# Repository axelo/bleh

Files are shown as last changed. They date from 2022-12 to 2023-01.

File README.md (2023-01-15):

# BLEH-1

Simple 8-bit processor with an 8-bit data bas, a 16-bit address bus and 8 in/out ports. Code and data is shared (Von Neumann architecture).

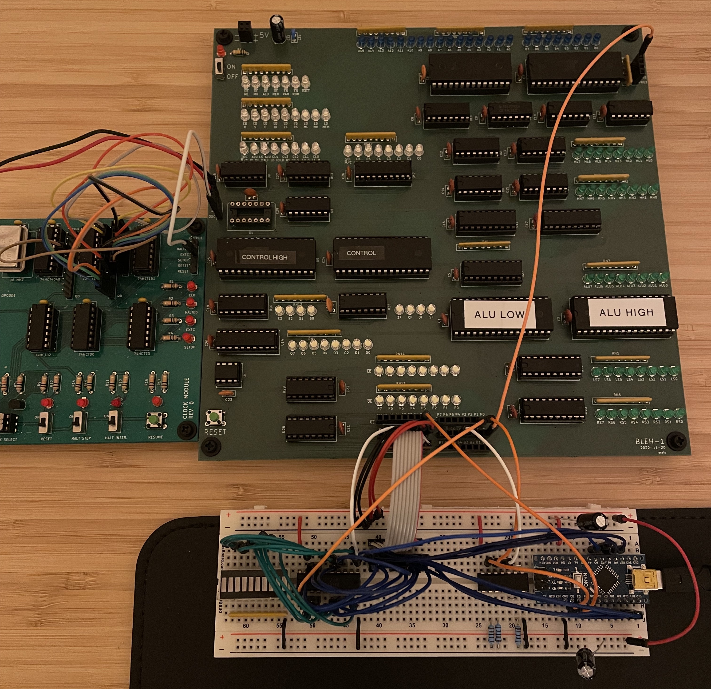
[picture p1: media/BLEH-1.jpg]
BLEH-1


## Videos

https://user-images.githubusercontent.com/40123/208307373-e6665b57-9ac1-4e1d-83b8-c3a5a47eff5f.mp4

https://user-images.githubusercontent.com/40123/209331055-dc162672-afca-4b18-9f8f-d3effcc05d64.mp4

## Logic blocks

### Memory backed registers

The last 16 bytes of memory are used for storing data and address registers (instruction registers) in addition to temporary storage during microcode steps.

8-bit data registers: `a`, `b`, `c` and `d`

16-bit address registers: `i` and `j`

8-bit special registers: `sp`

### ALU

Two 8-bit registers `LS` and `RS` makes up the operands to the ALU. Neither are accessible from software. Two ROMs makes up a lookup table for different ALU operation. A 4-bit flag register is available for storing `zf`, `cf`, `of` and `sf`.

### Control

Two ROMs together with a 4-bit step counter, an 8-bit opcode register and the flags register makes up a lookup table for different microcode steps for different instructions. The step counter is cleared on reset.

### Memory

Two 8-bit register `ML` and `MH` makes up the 16-bit address bus. Neither are accessible from software. The registers are cleared on reset making program execution start at `0x0000`.

#### Stack

The high part of the stack is locked at `0xff`. The low part is loaded by setting the `sp` instruction register. The stack grows upwards towards `0xffff`. Usually the `sp` is loaded with `0xff` making the first `push` at `0xff00`.

#### Constant and ML/MH toggle

One control signal toggles if the address bus is based on `ML`/`MH` or the low 4-bits of the constant register `or`:ed by `0xfff0`. This is used to address the instruction registers during microcode steps.

#### Memory map

    0x0000 - 0x7fff: ROM
    0x8000 - 0xfff0: RAM
    0xfff0 - 0xffff: RAM containing instruction registers

### Clock

The input clock source is divided into two equally long phases named setup and execute. The setup phase settles the control signals and the execute phase latches the input source (the data bus for example).

### Data bus

The data bus is pulled high so if nothing is asserted then `0xff` will be read.

## Software

### Compile

Requires that the `bleh_instructions.asm` [customasm](https://github.com/hlorenzi/customasm) ruledef file exists:

    ./compile_and_run.zsh customasm.c

Then compile your program using `customasm`, for example:

    customasm -q ./software/test_lcd.asm --print --format intelhex

### Loading software

Using the [arduino boot device](./arduino/BootDeviceSketch/BootDeviceSketch.ino), connect a serial monitor and paste Intel Hex format of the program.

## Emulator

### Compile

    ./compile.zsh emulator.c

### Run

Requires that the control and ALU ROM binaries are built:

    ./compile_and_run.zsh control.c && ./compile_and_run.zsh alu.c

Then compile your program using `customasm`:

    customasm <PROGRAM TO RUN>.asm --format binary --output <PROGRAM TO RUN>.bin

Then finally run the program using the emulator:

    ./bin/emulator <PROGRAM TO RUN>.bin [CLOCK FREQUENCY IN HZ]

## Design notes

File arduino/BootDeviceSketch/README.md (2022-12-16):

arduino-cli compile --fqbn arduino:avr:nano BootDeviceSketch/BootDeviceSketch.ino

arduino-cli upload -p /dev/cu.usbserial-10 --fqbn arduino:avr:nano:cpu=atmega328old BootDeviceSketch/BootDeviceSketch.ino

arduino-cli monitor -p /dev/cu.usbserial-10 -c baudrate=115200

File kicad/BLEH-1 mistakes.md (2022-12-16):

## Mistakes

### 1

D7 Led pin 2 is connected to BUS2, should be BUS1
D8 Led pin 2 is connected to BUS1, should be BUS2

### 2

U28 pin 9 connected to ~{LD} S, should be ~{LD} LS

### 3

All bypass capacitor footprints should be 5mm instead of 2.5mm.

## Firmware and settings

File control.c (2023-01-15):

#include <assert.h> // assert
#include <stdbool.h> // bool
#include <stdint.h> // uint*_t
#include <stdio.h> // FILE, f* functions

#include "alu_op.h"
#include "opcode.h"

#define CONTROL_ROM_SIZE (1 << 17)

#define PIN_OPCODE_0 0
#define PIN_OPCODE_1 1
#define PIN_OPCODE_2 2
#define PIN_OPCODE_3 3
#define PIN_OPCODE_4 4
#define PIN_OPCODE_5 5
#define PIN_OPCODE_6 6
#define PIN_OPCODE_7 7

#define PIN_HIGH_SLICE 10

#define PIN_FLAG_0_ZERO 11
#define PIN_FLAG_1_CARRY 9
#define PIN_FLAG_2_OVERFLOW 8
#define PIN_FLAG_3_SIGN 13

#define PIN_STEP_0 12
#define PIN_STEP_1 15
#define PIN_STEP_2 16
#define PIN_STEP_3 14

#define CE_M_NOT_LD_C (1 << 0)
#define LD_O_NOT_LD_C (1 << 1)
#define LD_S_NOT_LD_C (1 << 2)
#define LD_RS_NOT_LD_C (1 << 3)
#define LD_IO_NOT_LD_C (1 << 4)
#define C_LS_ALU_Q (1 << 5)
#define HALT_NOT_LD_C (1 << 5)
#define LD_C (1 << 6)
#define TG_M_C (1 << 7)
#define LD_MEM (1 << 8)
#define LD_LS (1 << 9)
#define LD_ML (1 << 10)
#define LD_MH (1 << 11)
#define OE_ML (1 << 12)
#define OE_MH (1 << 13)
#define OE_ALU (1 << 14)
#define OE_MEM (1 << 15)

#define ACTIVE_LOW_MASK (LD_C | LD_LS | LD_ML | LD_MH | OE_ML | OE_MH | OE_ALU | OE_MEM)

#define FETCH_OPCODE (OE_MEM | LD_O_NOT_LD_C | CE_M_NOT_LD_C)

#define C_A (0x0)
#define C_B (0x1)
#define C_C (0x2)
#define C_D (0x3)
#define C_SPL (0x4)
#define C_IL (0x5)
#define C_IH (0x6)
#define C_JL (0x7)
#define C_JH (0x8)
// #define C_ (0x9)
// #define C_ (0xa)
#define C_TL (0xb)
#define C_TH (0xc)
#define C_UL (0xd)
// #define C_ (0xe)
// #define C_ (0xf)

_Static_assert(ALU_OP_DEC_LS == C_SPL, "C_SPL must be identical to ALU_OP_DEC_LS");

static uint16_t opcode_nop(uint8_t step) {
    switch (step) {
    case 0: return FETCH_OPCODE;
    case 1: return 0;
    case 2: return 0;
    case 3: return 0;
    case 4: return 0;
    case 5: return 0;
    case 6: return 0;
    case 7: return LD_S_NOT_LD_C;
    default: return HALT_NOT_LD_C;
    }
}

static uint16_t opcode_halt(uint8_t step) {
    switch (step) {
    case 0: return FETCH_OPCODE;
    case 1: return HALT_NOT_LD_C;
    case 2: return LD_S_NOT_LD_C;
    default: return HALT_NOT_LD_C;
    }
}

static uint16_t opcode_ld_reg_imm8(uint8_t dest_const_reg, uint8_t step) {
    switch (step) {
    case 0: return FETCH_OPCODE;
    case 1: return OE_MEM | LD_LS | C_LS_ALU_Q | dest_const_reg | LD_C | TG_M_C;
    case 2: return OE_ALU | LD_MEM | TG_M_C | CE_M_NOT_LD_C | LD_S_NOT_LD_C;
    default: return HALT_NOT_LD_C;
    }
}

static uint16_t opcode_ld_index_imm16(uint8_t dest_const_index_l, uint8_t step) {
    switch (step) {
    case 0: return FETCH_OPCODE;
    case 1: return OE_MEM | LD_LS | C_LS_ALU_Q | dest_const_index_l | LD_C | TG_M_C;
    case 2: return OE_ALU | LD_MEM | TG_M_C | CE_M_NOT_LD_C;
    case 3: return OE_MEM | LD_LS | C_LS_ALU_Q | (dest_const_index_l + 1) | LD_C | TG_M_C;
    case 4: return OE_ALU | LD_MEM | TG_M_C | CE_M_NOT_LD_C | LD_S_NOT_LD_C;
    default: return HALT_NOT_LD_C;
    }
}

static uint16_t opcode_ld_reg_index_ptr(uint8_t dest_const_reg, uint8_t const_index_l, uint8_t step) {
    switch (step) {
    case 0: return FETCH_OPCODE;
    case 1: return C_TL | LD_C | TG_M_C;
    case 2: return OE_ML | LD_MEM | C_TH | LD_C;
    case 3: return OE_MH | LD_MEM | const_index_l | LD_C;
    case 4: return OE_MEM | LD_ML | (const_index_l + 1) | LD_C;
    case 5: return OE_MEM | LD_MH | TG_M_C;
    case 6: return OE_MEM | LD_LS | C_LS_ALU_Q | dest_const_reg | LD_C | TG_M_C;
    case 7: return OE_ALU | LD_MEM | C_TL | LD_C;
    case 8: return OE_MEM | LD_ML | C_TH | LD_C;
    case 9: return OE_MEM | LD_MH | TG_M_C | LD_S_NOT_LD_C;
    default: return HALT_NOT_LD_C;
    }
}

static uint16_t opcode_ld_reg_index_ptr_inc1(uint8_t dest_const_reg, uint8_t const_index_l, uint8_t step) {
    switch (step) {
    case 0: return FETCH_OPCODE;
    case 1: return C_TL | LD_C | TG_M_C;
    case 2: return OE_ML | LD_MEM | C_TH | LD_C;
    case 3: return OE_MH | LD_MEM | const_index_l | LD_C;
    case 4: return OE_MEM | LD_ML | (const_index_l + 1) | LD_C;
    case 5: return OE_MEM | LD_MH | TG_M_C;
    case 6: return OE_MEM | LD_LS | CE_M_NOT_LD_C | TG_M_C;
    case 7: return OE_MH | LD_MEM | const_index_l | LD_C;
    case 8: return OE_ML | LD_MEM | C_LS_ALU_Q | dest_const_reg | LD_C;
    case 9: return OE_ALU | LD_MEM | C_TL | LD_C;
    case 10: return OE_MEM | LD_ML | C_TH | LD_C;
    case 11: return OE_MEM | LD_MH | TG_M_C | LD_S_NOT_LD_C;
    default: return HALT_NOT_LD_C;
    }
}

static uint16_t opcode_ld_index_ptr_reg(uint8_t const_index_l, uint8_t dest_const_reg, uint8_t step) {
    switch (step) {
    case 0: return FETCH_OPCODE;
    case 1: return C_TL | LD_C | TG_M_C;
    case 2: return OE_ML | LD_MEM | C_TH | LD_C;
    case 3: return OE_MH | LD_MEM | const_index_l | LD_C;
    case 4: return OE_MEM | LD_ML | (const_index_l + 1) | LD_C;
    case 5: return OE_MEM | LD_MH | C_LS_ALU_Q | dest_const_reg | LD_C;
    case 6: return OE_MEM | LD_LS | TG_M_C;
    case 7: return OE_ALU | LD_MEM | C_TL | LD_C | TG_M_C;
    case 8: return OE_MEM | LD_ML | C_TH | LD_C;
    case 9: return OE_MEM | LD_MH | TG_M_C | LD_S_NOT_LD_C;
    default: return HALT_NOT_LD_C;
    }
}

static uint16_t opcode_ld_index_ptr_inc1_reg(uint8_t const_index_l, uint8_t dest_const_reg, uint8_t step) {
    switch (step) {
    case 0: return FETCH_OPCODE;
    case 1: return dest_const_reg | LD_C | TG_M_C;
    case 2: return OE_MEM | LD_LS | C_TL | LD_C;
    case 3: return OE_ML | LD_MEM | C_TH | LD_C;
    case 4: return OE_MH | LD_MEM | const_index_l | LD_C;
    case 5: return OE_MEM | LD_ML | C_LS_ALU_Q | (const_index_l + 1) | LD_C;
    case 6: return OE_MEM | LD_MH | TG_M_C;
    case 7: return OE_ALU | LD_MEM | CE_M_NOT_LD_C | TG_M_C;
    case 8: return OE_MH | LD_MEM | const_index_l | LD_C;
    case 9: return OE_ML | LD_MEM | C_TL | LD_C;
    case 10: return OE_MEM | LD_ML | C_TH | LD_C;
    case 11: return OE_MEM | LD_MH | TG_M_C | LD_S_NOT_LD_C;
    default: return HALT_NOT_LD_C;
    }
}

static uint16_t opcode_ld_index_ptr_reg_reg(uint8_t const_index_l, uint8_t src_const_reg_h, uint8_t src_const_reg_l, uint8_t step) {
    switch (step) {
    case 0: return FETCH_OPCODE;
    case 1: return C_TL | LD_C | TG_M_C;
    case 2: return OE_ML | LD_MEM | C_TH | LD_C;
    case 3: return OE_MH | LD_MEM | const_index_l | LD_C;
    case 4: return OE_MEM | LD_ML | (const_index_l + 1) | LD_C;
    case 5: return OE_MEM | LD_MH | C_LS_ALU_Q | src_const_reg_l | LD_C;
    case 6: return OE_MEM | LD_LS | TG_M_C;
    case 7: return OE_ALU | LD_MEM | C_LS_ALU_Q | src_const_reg_h | LD_C | TG_M_C;
    case 8: return OE_MEM | LD_LS | CE_M_NOT_LD_C | TG_M_C;
    case 9: return OE_ALU | LD_MEM | C_TL | LD_C | TG_M_C;
    case 10: return OE_MEM | LD_ML | C_TH | LD_C;
    case 11: return OE_MEM | LD_MH | TG_M_C | LD_S_NOT_LD_C;
    default: return HALT_NOT_LD_C;
    }
}

static uint16_t opcode_ld_reg_reg_index_ptr(uint8_t dest_const_reg_h, uint8_t dest_const_reg_l, uint8_t const_index_l, uint8_t step) {
    switch (step) {
    case 0: return FETCH_OPCODE;
    case 1: return C_TL | LD_C | TG_M_C;
    case 2: return OE_ML | LD_MEM | C_TH | LD_C;
    case 3: return OE_MH | LD_MEM | const_index_l | LD_C;
    case 4: return OE_MEM | LD_ML | (const_index_l + 1) | LD_C;
    case 5: return OE_MEM | LD_MH | C_LS_ALU_Q | dest_const_reg_l | LD_C | TG_M_C;
    case 6: return OE_MEM | LD_LS | CE_M_NOT_LD_C | TG_M_C;
    case 7: return OE_ALU | LD_MEM | C_LS_ALU_Q | dest_const_reg_h | LD_C | TG_M_C;
    case 8: return OE_MEM | LD_LS | TG_M_C;
    case 9: return OE_ALU | LD_MEM | C_TL | LD_C;
    case 10: return OE_MEM | LD_ML | C_TH | LD_C;
    case 11: return OE_MEM | LD_MH | TG_M_C | LD_S_NOT_LD_C;
    default: return HALT_NOT_LD_C;
    }
}

static u_int16_t opcode_ld_reg_reg(uint8_t dest_const_reg, uint8_t src_const_reg, uint8_t step) {
    switch (step) {
    case 0: return FETCH_OPCODE;
    case 1: return src_const_reg | LD_C | TG_M_C;
    case 2: return OE_MEM | LD_LS | C_LS_ALU_Q | dest_const_reg | LD_C;
    case 3: return OE_ALU | LD_MEM | TG_M_C | LD_S_NOT_LD_C;
    default: return HALT_NOT_LD_C;
    }
}

static uint16_t opcode_alu_op_reg(ALU_OP alu_op, uint8_t dest_and_src_const_reg, uint8_t step) {
    switch (step) {
    case 0: return FETCH_OPCODE;
    case 1: return dest_and_src_const_reg | LD_C | TG_M_C;
    case 2: return OE_MEM | LD_LS | (uint8_t)alu_op | LD_C;
    case 3: return OE_ALU | LD_LS | C_LS_ALU_Q | dest_and_src_const_reg | LD_C;
    case 4: return OE_ALU | LD_MEM | TG_M_C | LD_S_NOT_LD_C;
    default: return HALT_NOT_LD_C;
    }
}

static uint16_t opcode_alu_op_reg_reg(ALU_OP alu_op, uint8_t dest_const_reg, uint8_t src_const_reg, uint8_t step) {
    switch (step) {
    case 0: return FETCH_OPCODE;
    case 1: return dest_const_reg | LD_C | TG_M_C;
    case 2: return OE_MEM | LD_LS | src_const_reg | LD_C;
    case 3: return OE_MEM | LD_RS_NOT_LD_C;
    case 4: return (uint8_t)alu_op | LD_C;
    case 5: return OE_ALU | LD_LS | C_LS_ALU_Q | dest_const_reg | LD_C;
    case 6: return OE_ALU | LD_MEM | TG_M_C | LD_S_NOT_LD_C;
    default: return HALT_NOT_LD_C;
    }
}

static uint16_t opcode_alu_op_reg_imm8(ALU_OP alu_op, uint8_t dest_const_reg, uint8_t step) {
    switch (step) {
    case 0: return FETCH_OPCODE;
    case 1: return OE_MEM | LD_RS_NOT_LD_C | CE_M_NOT_LD_C;
    case 2: return dest_const_reg | LD_C | TG_M_C;
    case 3: return OE_MEM | LD_LS | (uint8_t)alu_op | LD_C;
    case 4: return OE_ALU | LD_LS | C_LS_ALU_Q | dest_const_reg | LD_C;
    case 5: return OE_ALU | LD_MEM | TG_M_C | LD_S_NOT_LD_C;
    default: return HALT_NOT_LD_C;
    }
}

static uint16_t opcode_alu_cmp_reg_imm8(uint8_t const_reg, uint8_t step) {
    switch (step) {
    case 0: return FETCH_OPCODE;
    case 1: return OE_MEM | LD_RS_NOT_LD_C | CE_M_NOT_LD_C;
    case 2: return const_reg | LD_C | TG_M_C;
    case 3: return OE_MEM | LD_LS | ALU_OP_LS_SUB_RS | LD_C;
    case 4: return OE_ALU | LD_LS | TG_M_C | LD_S_NOT_LD_C;
    default: return HALT_NOT_LD_C;
    }
}

static uint16_t opcode_jmp_imm16(uint8_t step) {
    switch (step) {
    case 0: return FETCH_OPCODE;
    case 1: return OE_MEM | LD_LS | CE_M_NOT_LD_C;
    case 2: return OE_MEM | LD_MH | C_LS_ALU_Q | LD_C;
    case 3: return OE_ALU | LD_ML | LD_S_NOT_LD_C;
    default: return HALT_NOT_LD_C;
    }
}

static uint16_t opcode_jmp_index(uint8_t const_index_l, uint8_t step) {
    switch (step) {
    case 0: return FETCH_OPCODE;
    case 1: return const_index_l | LD_C | TG_M_C;
    case 2: return OE_MEM | LD_ML | (const_index_l + 1) | LD_C;
    case 3: return OE_MEM | LD_MH | LD_S_NOT_LD_C | TG_M_C;
    default: return HALT_NOT_LD_C;
    }
}

static u_int16_t opcode_jmp_condition_imm16(bool condition, uint8_t step) {
    if (condition) {
        switch (step) {
        case 0: return FETCH_OPCODE;
        case 1: return OE_MEM | LD_LS | CE_M_NOT_LD_C;
        case 2: return OE_MEM | LD_MH | C_LS_ALU_Q | LD_C;
        case 3: return OE_ALU | LD_ML | LD_S_NOT_LD_C;
        default: return HALT_NOT_LD_C;
        }
    } else {
        switch (step) {
        case 0: return FETCH_OPCODE;
        case 1: return CE_M_NOT_LD_C;
        case 2: return CE_M_NOT_LD_C;
        case 3: return LD_S_NOT_LD_C;
        default: return HALT_NOT_LD_C;
        }
    }
}

static uint16_t opcode_push_reg(uint8_t src_const_reg, uint8_t step) {
    switch (step) {
    case 0: return FETCH_OPCODE;
    case 1: return C_TL | LD_C | TG_M_C;
    case 2: return OE_ML | LD_MEM | C_TH | LD_C;
    case 3: return OE_MH | LD_MEM | C_SPL | LD_C;
    case 4: return OE_MEM | LD_ML;
    case 5: return LD_MH | CE_M_NOT_LD_C;
    case 6: return OE_ML | LD_MEM | C_LS_ALU_Q | src_const_reg | LD_C;
    case 7: return OE_MEM | LD_LS | TG_M_C;
    case 8: return OE_ALU | LD_MEM | C_TL | LD_C | TG_M_C;
    case 9: return OE_MEM | LD_ML | C_TH | LD_C;
    case 10: return OE_MEM | LD_MH | TG_M_C | LD_S_NOT_LD_C;
    default: return HALT_NOT_LD_C;
    }
}

static uint16_t opcode_pop_reg(uint8_t dest_const_reg, uint8_t step) {
    switch (step) {
    case 0: return FETCH_OPCODE;
    case 1: return C_TL | LD_C | TG_M_C;
    case 2: return OE_ML | LD_MEM | C_TH | LD_C;
    case 3: return OE_MH | LD_MEM | C_SPL | LD_C; // ALU_OP_DEC_LS at the same time
    case 4: return OE_MEM | LD_ML | LD_LS;
    case 5: return OE_ALU | LD_MEM; // --sp
    case 6: return LD_MH | TG_M_C; // MH = 0xff
    case 7: return OE_MEM | LD_LS | C_LS_ALU_Q | dest_const_reg | LD_C | TG_M_C;
    case 8: return OE_ALU | LD_MEM | C_TL | LD_C;
    case 9: return OE_MEM | LD_ML | C_TH | LD_C;
    case 10: return OE_MEM | LD_MH | TG_M_C | LD_S_NOT_LD_C;
    default: return HALT_NOT_LD_C;
    }
}

static uint16_t opcode_push_index(uint8_t src_const_index_l, uint8_t step) {
    switch (step) {
    case 0: return FETCH_OPCODE;
    case 1: return C_TL | LD_C | TG_M_C;
    case 2: return OE_ML | LD_MEM | C_TH | LD_C;
    case 3: return OE_MH | LD_MEM | C_SPL | LD_C;
    case 4: return OE_MEM | LD_ML | src_const_index_l | LD_C;
    case 5: return LD_MH | CE_M_NOT_LD_C;
    case 6: return OE_MEM | LD_LS | C_LS_ALU_Q | (src_const_index_l + 1) | LD_C | TG_M_C;
    case 7: return OE_ALU | LD_MEM | CE_M_NOT_LD_C | TG_M_C;
    case 8: return OE_MEM | LD_LS | TG_M_C;
    case 9: return OE_ALU | LD_MEM | C_SPL | LD_C | TG_M_C;
    case 10: return OE_ML | LD_MEM | C_TL | LD_C;
    case 11: return OE_MEM | LD_ML | C_TH | LD_C;
    case 12: return OE_MEM | LD_MH | TG_M_C | LD_S_NOT_LD_C;
    default: return HALT_NOT_LD_C;
    }
}

static uint16_t opcode_pop_index(uint8_t dest_const_index_l, uint8_t step) {
    switch (step) {
    case 0: return FETCH_OPCODE;
    case 1: return C_TL | LD_C | TG_M_C;
    case 2: return OE_ML | LD_MEM | C_TH | LD_C;
    case 3: return OE_MH | LD_MEM | C_SPL | LD_C; // ALU_OP_DEC_LS at the same time
    case 4: return OE_MEM | LD_ML | LD_LS;
    case 5: return OE_ALU | LD_MEM; // --sp
    case 6: return LD_MH | TG_M_C;
    case 7: return OE_MEM | LD_LS | C_LS_ALU_Q | (dest_const_index_l + 1) | LD_C | TG_M_C;
    case 8: return OE_ALU | LD_MEM | C_SPL | LD_C;
    case 9: return OE_MEM | LD_ML | LD_LS;
    case 10: return OE_ALU | LD_MEM | TG_M_C; // --sp
    case 11: return OE_MEM | LD_LS | C_LS_ALU_Q | dest_const_index_l | LD_C | TG_M_C;
    case 12: return OE_ALU | LD_MEM | C_TL | LD_C;
    case 13: return OE_MEM | LD_ML | C_TH | LD_C;
    case 14: return OE_MEM | LD_MH | TG_M_C | LD_S_NOT_LD_C;
    default: return HALT_NOT_LD_C;
    }
}

static uint16_t opcode_call_imm16(uint8_t step) {
    switch (step) {
    case 0: return FETCH_OPCODE;
    case 1: return OE_MEM | LD_LS | C_LS_ALU_Q | C_TL | LD_C | TG_M_C;
    case 2: return OE_ALU | LD_MEM | TG_M_C | CE_M_NOT_LD_C;
    case 3: return OE_MEM | LD_LS | C_LS_ALU_Q | C_TH | LD_C | TG_M_C;
    case 4: return OE_ALU | LD_MEM | CE_M_NOT_LD_C;
    case 5: return OE_ML | LD_LS | C_UL | LD_C;
    case 6: return OE_MH | LD_MEM | C_SPL | LD_C;
    case 7: return OE_MEM | LD_ML | C_LS_ALU_Q | C_UL | LD_C;
    case 8: return LD_MH | CE_M_NOT_LD_C | TG_M_C;
    case 9: return OE_ALU | LD_MEM | CE_M_NOT_LD_C | TG_M_C;
    case 10: return OE_MEM | LD_LS | TG_M_C;
    case 11: return OE_ALU | LD_MEM | C_SPL | LD_C | TG_M_C;
    case 12: return OE_ML | LD_MEM | C_TL | LD_C;
    case 13: return OE_MEM | LD_ML | C_TH | LD_C;
    case 14: return OE_MEM | LD_MH | TG_M_C | LD_S_NOT_LD_C;
    default: return HALT_NOT_LD_C;
    }
}

static uint16_t opcode_ret(uint8_t step) {
    switch (step) {
    case 0: return FETCH_OPCODE;
    case 1: return C_SPL | LD_C | TG_M_C; // ALU_OP_DEC_LS at the same time
    case 2: return OE_MEM | LD_ML | LD_LS;
    case 3: return OE_ALU | LD_MEM; // --sp
    case 4: return LD_MH | TG_M_C;
    case 5: return OE_MEM | LD_LS | C_LS_ALU_Q | C_TH | LD_C | TG_M_C;
    case 6: return OE_ALU | LD_MEM | C_SPL | LD_C;
    case 7: return OE_MEM | LD_ML | LD_LS;
    case 8: return OE_ALU | LD_MEM | TG_M_C; // --sp
    case 9: return OE_MEM | LD_ML | C_TH | LD_C | TG_M_C;
    case 10: return OE_MEM | LD_MH | TG_M_C | LD_S_NOT_LD_C;
    default: return HALT_NOT_LD_C;
    }
}

static uint16_t opcode_ld_reg_sp_plus_imm8_ptr(uint8_t dest_const_reg, uint8_t step) {
    switch (step) {
    case 0: return FETCH_OPCODE;
    case 1: return OE_MEM | LD_RS_NOT_LD_C | CE_M_NOT_LD_C; // RS = imm
    case 2: return C_TL | LD_C | TG_M_C;
    case 3: return OE_ML | LD_MEM | C_TH | LD_C;
    case 4: return OE_MH | LD_MEM | C_SPL | LD_C;
    case 5: return OE_MEM | LD_LS | ALU_OP_LS_ADD_RS | LD_C; // LS = sp
    case 6: return OE_ALU | LD_ML; // ML = (sp + imm) & 0xff
    case 7: return LD_MH | TG_M_C;
    case 8: return OE_MEM | LD_LS | C_LS_ALU_Q | dest_const_reg | LD_C | TG_M_C;
    case 9: return OE_ALU | LD_MEM | C_TL | LD_C;
    case 10: return OE_MEM | LD_ML | C_TH | LD_C;
    case 11: return OE_MEM | LD_MH | TG_M_C | LD_S_NOT_LD_C;
    default: return HALT_NOT_LD_C;
    }
}

static uint16_t opcode_in_reg_port(uint8_t dest_const_reg, uint8_t step) {
    switch (step) {
    case 0: return FETCH_OPCODE;
    case 1: return ALU_OP_SET_IO_OE_FLAG | LD_C | TG_M_C;
    case 2: return LD_C;
    case 3: return LD_LS | C_LS_ALU_Q | dest_const_reg | LD_C;
    case 4: return OE_ALU | LD_MEM | TG_M_C | LD_S_NOT_LD_C;
    default: return HALT_NOT_LD_C;
    }
}

static uint16_t opcode_out_port_reg(uint8_t src_const_reg, uint8_t step) {
    switch (step) {
    case 0: return FETCH_OPCODE;
    case 1: return src_const_reg | LD_C | TG_M_C;
    case 2: return OE_MEM | LD_IO_NOT_LD_C;
    case 3: return TG_M_C | LD_S_NOT_LD_C;
    default: return HALT_NOT_LD_C;
    }
}

static uint16_t opcode_out_port_imm8(uint8_t step) {
    switch (step) {
    case 0: return FETCH_OPCODE;
    case 1: return OE_MEM | LD_IO_NOT_LD_C;
    case 2: return CE_M_NOT_LD_C | LD_S_NOT_LD_C;
    default: return HALT_NOT_LD_C;
    }
}
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
int main(void) {
    uint8_t table[CONTROL_ROM_SIZE];

    generate_table(&table);

    return write_to_file("./bin/control.bin", &table);
}

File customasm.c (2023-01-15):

#include <assert.h>
#include <stdio.h>
#include <time.h>

#include "opcode.h"

typedef enum {
    NONE,
    PORT,
    PORT_IMM8,
    PORT_A,
    IMM8,
    IMM16
} Operand;

typedef struct {
    const char *n;
    Operand op;
} Rule;

static inline Rule rule(const char *name, Operand operand) {
    return (Rule){.n = name, .op = operand};
}

static Rule rule_from_opcode(Opcode opcode) {
    switch (opcode) {
    case OPCODE_NOP: return rule("nop", NONE);
    case OPCODE_LD_A_IMM8: return rule("ld a,", IMM8);
    case OPCODE_LD_B_IMM8: return rule("ld b,", IMM8);
    case OPCODE_LD_C_IMM8: return rule("ld c,", IMM8);
    case OPCODE_LD_D_IMM8: return rule("ld d,", IMM8);
    case OPCODE_LD_I_IMM16: return rule("ld i,", IMM16);
    case OPCODE_LD_J_IMM16: return rule("ld j,", IMM16);
    case OPCODE_LD_A_I_PTR: return rule("ld a, [i]", NONE);
    case OPCODE_LD_A_J_PTR: return rule("ld a, [j]", NONE);
    case OPCODE_LD_A_I_PTR_INC1: return rule("ld a, [i++]", NONE);
    case OPCODE_LD_A_J_PTR_INC1: return rule("ld a, [j++]", NONE);
    case OPCODE_LD_I_PTR_A: return rule("ld [i], a", NONE);
    case OPCODE_LD_J_PTR_A: return rule("ld [j], a", NONE);
    case OPCODE_LD_I_PTR_INC1_A: return rule("ld [i++], a", NONE);
    case OPCODE_LD_J_PTR_INC1_A: return rule("ld [j++], a", NONE);
    case OPCODE_LD_I_PTR_AB: return rule("ld [i], ab", NONE);
    case OPCODE_LD_I_PTR_CD: return rule("ld [i], cd", NONE);
    case OPCODE_LD_J_PTR_CD: return rule("ld [j], cd", NONE);
    case OPCODE_LD_AB_I_PTR: return rule("ld ab, [i]", NONE);
    case OPCODE_LD_CD_I_PTR: return rule("ld cd, [i]", NONE);
    case OPCODE_LD_CD_J_PTR: return rule("ld cd, [j]", NONE);
    case OPCODE_LD_A_B: return rule("ld a, b", NONE);
    case OPCODE_LD_A_C: return rule("ld a, c", NONE);
    case OPCODE_LD_A_D: return rule("ld a, d", NONE);
    case OPCODE_LD_B_A: return rule("ld b, a", NONE);
    case OPCODE_LD_B_C: return rule("ld b, c", NONE);
    case OPCODE_LD_B_D: return rule("ld b, d", NONE);
    case OPCODE_LD_C_A: return rule("ld c, a", NONE);
    case OPCODE_LD_C_B: return rule("ld c, b", NONE);
    case OPCODE_LD_C_D: return rule("ld c, d", NONE);
    case OPCODE_LD_D_A: return rule("ld d, a", NONE);
    case OPCODE_LD_D_B: return rule("ld d, b", NONE);
    case OPCODE_LD_D_C: return rule("ld d, c", NONE);
    case OPCODE_INC_A: return rule("inc a", NONE);
    case OPCODE_SHL_A: return rule("shl a", NONE);
    case OPCODE_SHR_A: return rule("shr a", NONE);
    case OPCODE_NOT_A: return rule("not a", NONE);
    case OPCODE_DEC_A: return rule("dec a", NONE);
    case OPCODE_ROR_A: return rule("ror a", NONE);
    case OPCODE_ADD_A_B: return rule("add a, b", NONE);
    case OPCODE_OR_A_B: return rule("or a, b", NONE);
    case OPCODE_AND_A_B: return rule("and a, b", NONE);
    case OPCODE_XOR_A_B: return rule("xor a, b", NONE);
    case OPCODE_ADC_A_B: return rule("adc a, b", NONE);
    case OPCODE_DEC_B: return rule("dec b", NONE);
    case OPCODE_DEC_C: return rule("dec c", NONE);
    case OPCODE_DEC_D: return rule("dec d", NONE);
    case OPCODE_INC_B: return rule("inc b", NONE);
    case OPCODE_INC_C: return rule("inc c", NONE);
    case OPCODE_INC_D: return rule("inc d", NONE);
    case OPCODE_ADD_D_B: return rule("add d, b", NONE);
    case OPCODE_ADC_C_A: return rule("adc c, a", NONE);
    case OPCODE_ADC_D_IMM8: return rule("adc d,", IMM8);
    case OPCODE_ADD_A_IMM8: return rule("add a,", IMM8);
    case OPCODE_OR_A_IMM8: return rule("or a,", IMM8);
    case OPCODE_AND_A_IMM8: return rule("and a,", IMM8);
    case OPCODE_XOR_A_IMM8: return rule("xor a,", IMM8);
    case OPCODE_ADC_A_IMM8: return rule("adc a,", IMM8);
    case OPCODE_ADD_B_IMM8: return rule("add b,", IMM8);
    case OPCODE_CMP_A_IMM8: return rule("cmp a,", IMM8);
    case OPCODE_CMP_B_IMM8: return rule("cmp b,", IMM8);
    case OPCODE_OUT_PORT0_IMM8: assert((opcode & 7) == 0); return rule("out", PORT_IMM8);
    case OPCODE_OUT_PORT1_IMM8:
        assert(opcode - 1 == OPCODE_OUT_PORT0_IMM8);
        assert((opcode & 7) == 1);
        return rule("", NONE);
    case OPCODE_OUT_PORT2_IMM8:
        assert(opcode - 1 == OPCODE_OUT_PORT1_IMM8);
        assert((opcode & 7) == 2);
        return rule("", NONE);
    case OPCODE_OUT_PORT3_IMM8:
        assert(opcode - 1 == OPCODE_OUT_PORT2_IMM8);
        assert((opcode & 7) == 3);
        return rule("", NONE);
    case OPCODE_OUT_PORT4_IMM8:
        assert(opcode - 1 == OPCODE_OUT_PORT3_IMM8);
        assert((opcode & 7) == 4);
        return rule("", NONE);
    case OPCODE_OUT_PORT5_IMM8:
        assert(opcode - 1 == OPCODE_OUT_PORT4_IMM8);
        assert((opcode & 7) == 5);
        return rule("", NONE);
    case OPCODE_OUT_PORT6_IMM8:
        assert(opcode - 1 == OPCODE_OUT_PORT5_IMM8);
        assert((opcode & 7) == 6);
        return rule("", NONE);
    case OPCODE_OUT_PORT7_IMM8:
        assert(opcode - 1 == OPCODE_OUT_PORT6_IMM8);
        assert((opcode & 7) == 7);
        return rule("", NONE);
    case OPCODE_IN_A_PORT0: assert((opcode & 7) == 0); return rule("in a,", PORT);
    case OPCODE_IN_A_PORT1:
        assert(opcode - 1 == OPCODE_IN_A_PORT0);
        assert((opcode & 7) == 1);
        return rule("", NONE);
    case OPCODE_IN_A_PORT2:
        assert(opcode - 1 == OPCODE_IN_A_PORT1);
        assert((opcode & 7) == 2);
        return rule("", NONE);
    case OPCODE_IN_A_PORT3:
        assert(opcode - 1 == OPCODE_IN_A_PORT2);
        assert((opcode & 7) == 3);
        return rule("", NONE);
    case OPCODE_IN_A_PORT4:
        assert(opcode - 1 == OPCODE_IN_A_PORT3);
        assert((opcode & 7) == 4);
        return rule("", NONE);
    case OPCODE_IN_A_PORT5:
        assert(opcode - 1 == OPCODE_IN_A_PORT4);
        assert((opcode & 7) == 5);
        return rule("", NONE);
    case OPCODE_IN_A_PORT6:
        assert(opcode - 1 == OPCODE_IN_A_PORT5);
        assert((opcode & 7) == 6);
        return rule("", NONE);
    case OPCODE_IN_A_PORT7:
        assert(opcode - 1 == OPCODE_IN_A_PORT6);
        assert((opcode & 7) == 7);
        return rule("", NONE);
    case OPCODE_OUT_PORT0_A: assert((opcode & 7) == 0); return rule("out", PORT_A);
    case OPCODE_OUT_PORT1_A:
        assert(opcode - 1 == OPCODE_OUT_PORT0_A);
        assert((opcode & 7) == 1);
        return rule("", NONE);
    case OPCODE_OUT_PORT2_A:
        assert(opcode - 1 == OPCODE_OUT_PORT1_A);
        assert((opcode & 7) == 2);
        return rule("", NONE);
    case OPCODE_OUT_PORT3_A:
        assert(opcode - 1 == OPCODE_OUT_PORT2_A);
        assert((opcode & 7) == 3);
        return rule("", NONE);
    case OPCODE_OUT_PORT4_A:
        assert(opcode - 1 == OPCODE_OUT_PORT3_A);
        assert((opcode & 7) == 4);
        return rule("", NONE);
    case OPCODE_OUT_PORT5_A:
        assert(opcode - 1 == OPCODE_OUT_PORT4_A);
        assert((opcode & 7) == 5);
        return rule("", NONE);
    case OPCODE_OUT_PORT6_A:
        assert(opcode - 1 == OPCODE_OUT_PORT5_A);
        assert((opcode & 7) == 6);
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

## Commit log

2022-12-04 Support simple boot device (#1)
2022-12-16 Boot device (#2)
